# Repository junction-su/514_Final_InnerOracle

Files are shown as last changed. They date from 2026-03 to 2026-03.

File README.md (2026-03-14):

# 🔮 InnerOracle: Biometric Fortune Teller

## 1. Project Overview
**InnerOracle** is an interactive, tangible interface that translates physiological stress into mystical guidance. Unlike traditional fortune-telling machines that rely on random chance, InnerOracle utilizes **Galvanic Skin Response (GSR)** to measure the user's emotional arousal and provides a personalized Tarot reading through a mechanical dial and an OLED display.

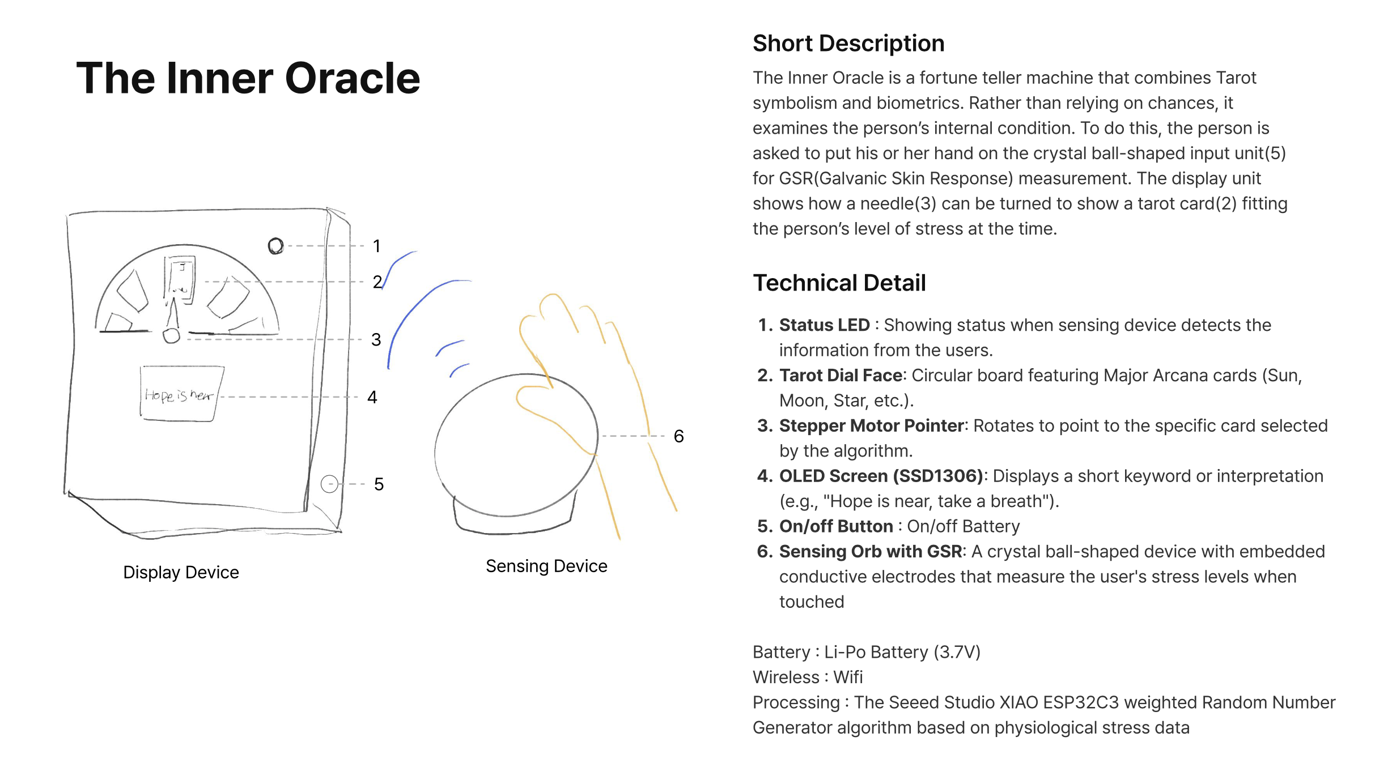
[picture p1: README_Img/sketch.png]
Concept Sketch
 

## 2. Technical Complexity & System Architecture
The system is built with a **Dual-Node Architecture** using two Seeed Studio XIAO ESP32-C3 microcontrollers communicating via the **ESP-NOW** wireless protocol.

### [Sensing Node]
* **Microcontroller**: Seeed Studio XIAO ESP32-C3
* **Sensor**: Grove GSR Sensor with custom Copper Tape Electrodes
* **Logic**: Implements an **Adaptive Baseline Tracking** algorithm to detect emotional triggers beyond skin resistance fluctuations.
* **Feedback**: Provides immediate visual feedback via NeoPixel LED (Rainbow effect).

### [Display Node]
* **Microcontroller**: Seeed Studio XIAO ESP32-C3
* **Actuator**: **X27.168 Stepper Motor** (Precision Gauge Motor)
* **Display**: 0.96" I2C SSD1306 OLED
* **Logic**: Receives real-time stress data and controls the physical needle with custom homing and calibration sequences.

## 3. Data Flow
`[User's Hand] -> [GSR Sensor] -> [Sensing XIAO] --(ESP-NOW Wireless)--> [Display XIAO] -> [X27 Motor & OLED]`

## 4. Hardware Fabrication
* **Custom PCB**: Designed and soldered at GIX Prototyping Labs.
* **Enclosure**: 2-part 3D printed housing ("The Orb" and "The Dial Box").
* **Power**: Powered by 3.7V 1000mAh LiPo batteries, optimized for up to 150+ hours of typical usage.

## 5. Repository Structure
* `/Sensing_Node`: Source code for GSR data processing and ESP-NOW transmission.
* `/Display_Node`: Source code for motor control, OLED UI, and data reception.

## 6. Budget Summary
* Total Project Cost: **$66.95**
* Key Components: GSR Sensor ($32.99), 1000mAh Batteries ($16.98), XIAO ESP32C3 ($10.99).

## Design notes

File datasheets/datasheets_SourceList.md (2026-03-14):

- Gear Stepper Motor(x27.168) : https://cdn-shop.adafruit.com/product-files/2424/2424.pdf // http://agr.ucoz.lv/files/SP_X27_e_C.pdf
- SSD1306(OLED) : https://cdn-shop.adafruit.com/datasheets/SSD1306.pdf
- Grove - GSR Sensor (Seeed Studio) : https://files.seeedstudio.com/wiki/Grove-GSR_Sensor/res/Grove-GSR_Sensor_WiKi.pdf
- ESP32-C3 : https://files.seeedstudio.com/wiki/XIAO_WiFi/Resources/esp32-c3_datasheet.pdf
- Li-Po Battery : https://cdn-shop.adafruit.com/product-files/1578/Datasheet.pdf
- Push Button(Tactile_Button_6mm) : https://cdn-shop.adafruit.com/datasheets/B3F-1000-Omron.pdf
- WS2812B(LED) : https://cdn-shop.adafruit.com/datasheets/WS2812B.pdf

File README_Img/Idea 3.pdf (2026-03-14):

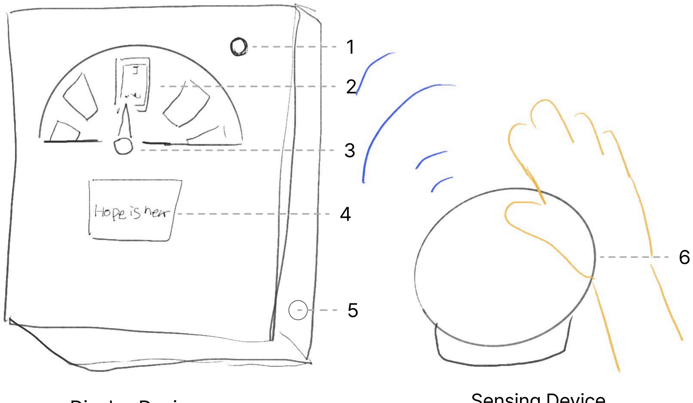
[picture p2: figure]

### Sensing Device Display Device

The Inner Oracle | Short Description

## Technical Detail

The Inner Oracle is a fortune teller machine that combines Tarot symbolism and biometrics. Rather than relying on chances, it examines the personˇs internal condition. To do this, the person is asked to put his or her hand on the crystal ball-shaped input unit(5) for GSR(Galvanic Skin Response) measurement. The display unit shows how a needle(3) can be turned to show a tarot card(2) fitting the personˇs level of stress at the time.

Status LED : Showing status when sensing device detects the information from the users.
Tarot Dial Face: Circular board featuring Major Arcana cards (Sun, Moon, Star, etc.).
Stepper Motor Pointer: Rotates to point to the specific card selected by the algorithm.
OLED Screen (SSD1306): Displays a short keyword or interpretation (e.g., "Hope is near, take a breath").
On/off Button : On/off Battery
Sensing Orb with GSR: A crystal ball-shaped device with embedded conductive electrodes that measure the user's stress levels when touched

Battery : Li-Po Battery (3.7V)
Wireless : Wifi
Processing : The Seeed Studio XIAO ESP32C3 weighted Random Number Generator algorithm based on physiological stress dat

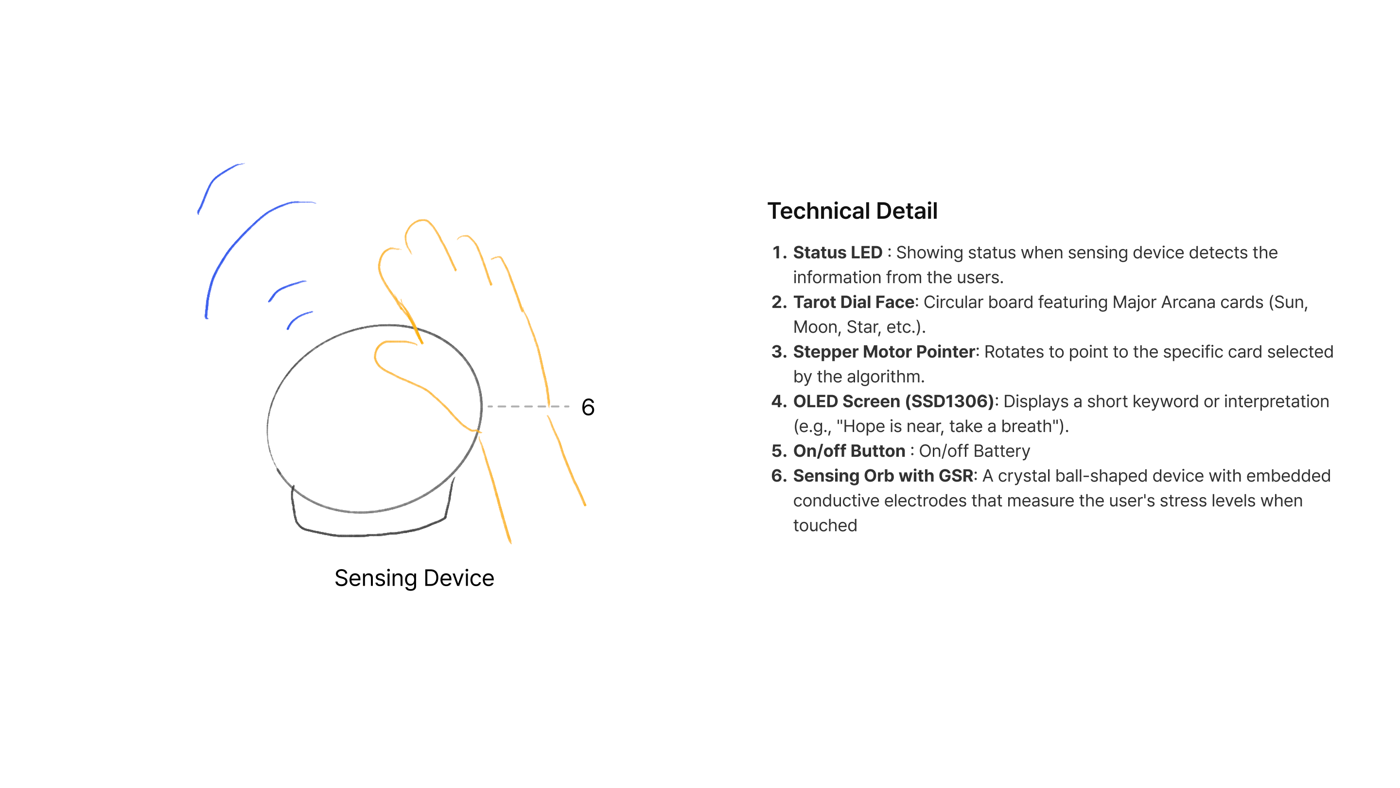
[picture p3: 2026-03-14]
README_Img/sensor_detail.png

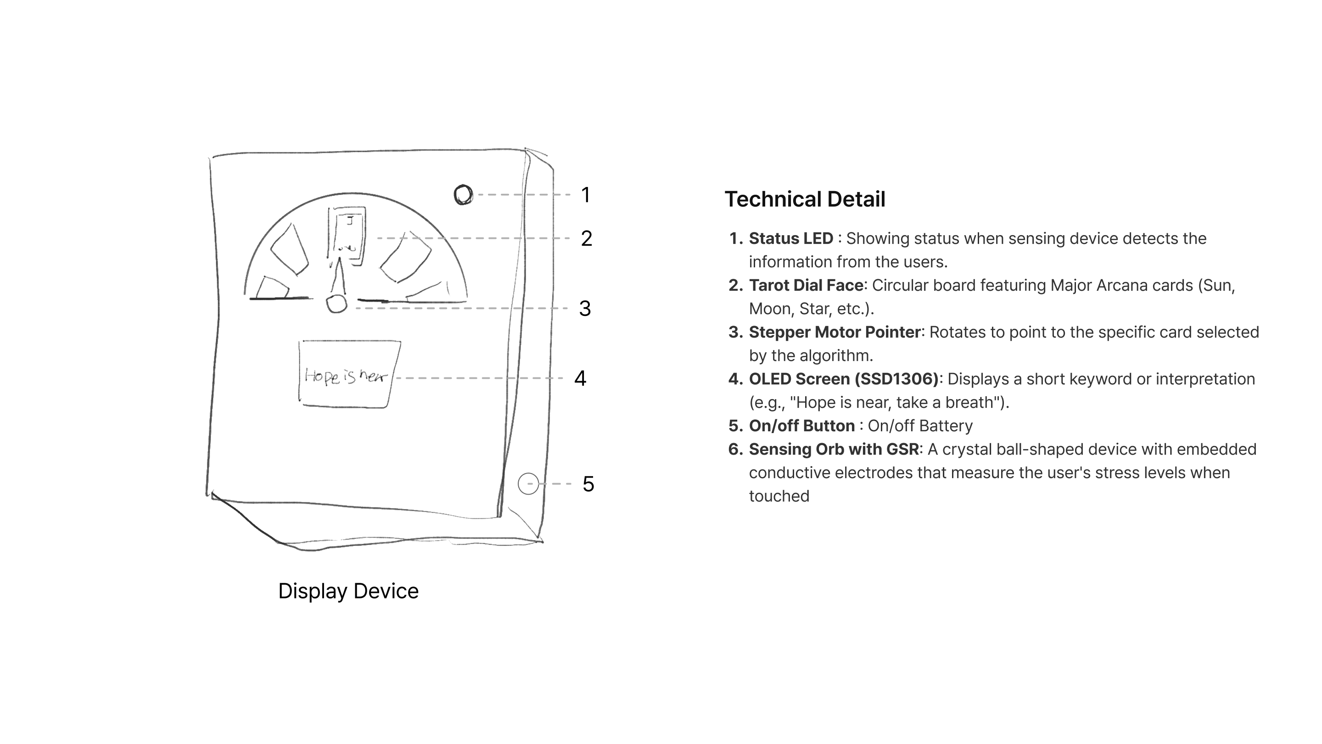
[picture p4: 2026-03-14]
README_Img/display_detail.png

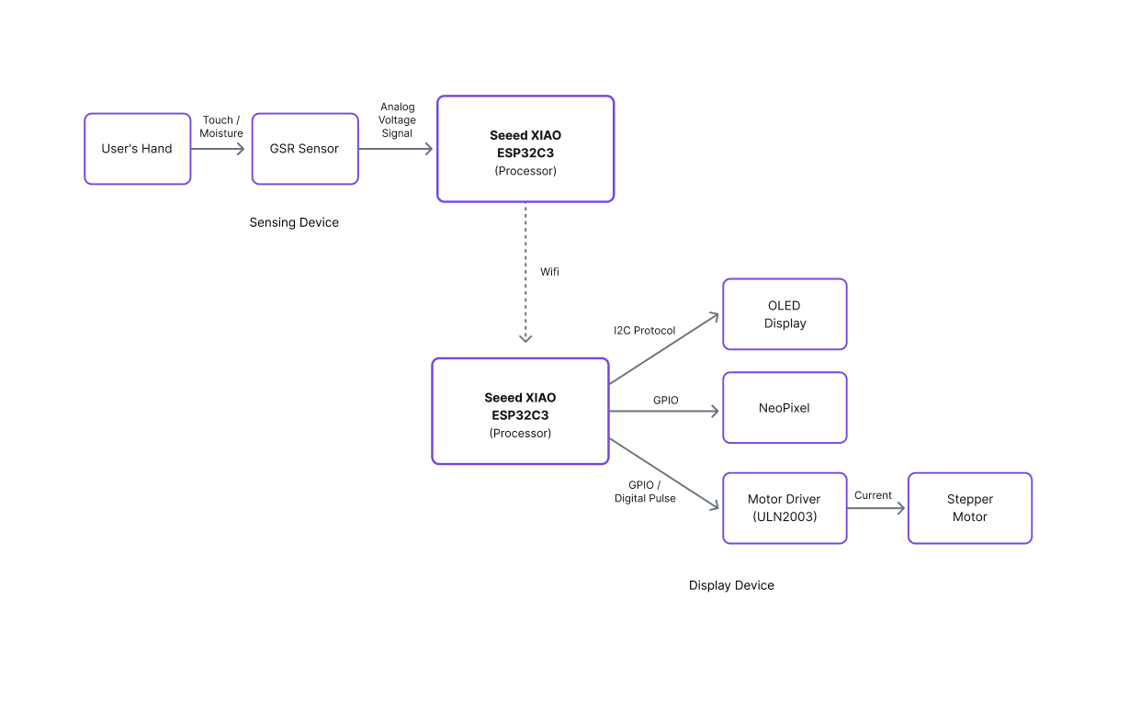
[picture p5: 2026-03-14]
README_Img/system_diagram_1.png

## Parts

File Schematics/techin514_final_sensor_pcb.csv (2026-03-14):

# | Reference | Qty | Value | Footprint | DNP
1 | Brd1 | 1 | SSD1306 | SSD1306:128x64OLED
2 | BT1, BT2 | 2 | Battery_Cell | Connector_JST:JST_PH_B2B-PH-K_1x02_P2.00mm_Vertical
3 | D1 | 1 | NeoPixel_THT | LED_THT:LED_Rectangular_W5.0mm_H2.0mm-3Pins
4 | J1 | 1 | SMD Grove | Connector:NS-Tech_Grove_1x04_P2mm_Vertical
5 | M1 | 1 | Stepper_Motor_bipolar | x27_stepper:x27_stepper_two_holes
6 | SW1, SW2 | 2 | SW_Push | Button_Switch_THT:SW_PUSH_6mm
7 | U1, U2 | 2 | ESP32-C3-XIAO | esp32c3:XIAO_ESP32

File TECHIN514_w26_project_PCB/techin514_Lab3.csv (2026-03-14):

# | Reference | Qty | Value | Footprint | DNP
1 | C1, C2 | 2 | 1uf | Capacitor_SMD:C_0805_2012Metric_Pad1.18x1.45mm_HandSolder
2 | C3 | 1 | 0.1uf | Capacitor_SMD:C_0805_2012Metric_Pad1.18x1.45mm_HandSolder
3 | C4 | 1 | 4.7uf | Capacitor_SMD:C_0805_2012Metric_Pad1.18x1.45mm_HandSolder
4 | D1 | 1 | LED | LED_SMD:LED_0805_2012Metric_Pad1.15x1.40mm_HandSolder
5 | J1 | 1 | Conn_01x04_Pin | Connector_PinSocket_2.54mm:PinSocket_1x04_P2.54mm_Vertical
6 | R1, R2 | 2 | 10k | Resistor_SMD:R_0805_2012Metric_Pad1.20x1.40mm_HandSolder
7 | R3 | 1 | 1k | Resistor_SMD:R_0805_2012Metric_Pad1.20x1.40mm_HandSolder
8 | U1 | 1 | MIC5376 | Package_TO_SOT_SMD:SOT-23-5
9 | U2 | 1 | LTR390 | OptoDevice:Lite-On_LTR-303ALS-01

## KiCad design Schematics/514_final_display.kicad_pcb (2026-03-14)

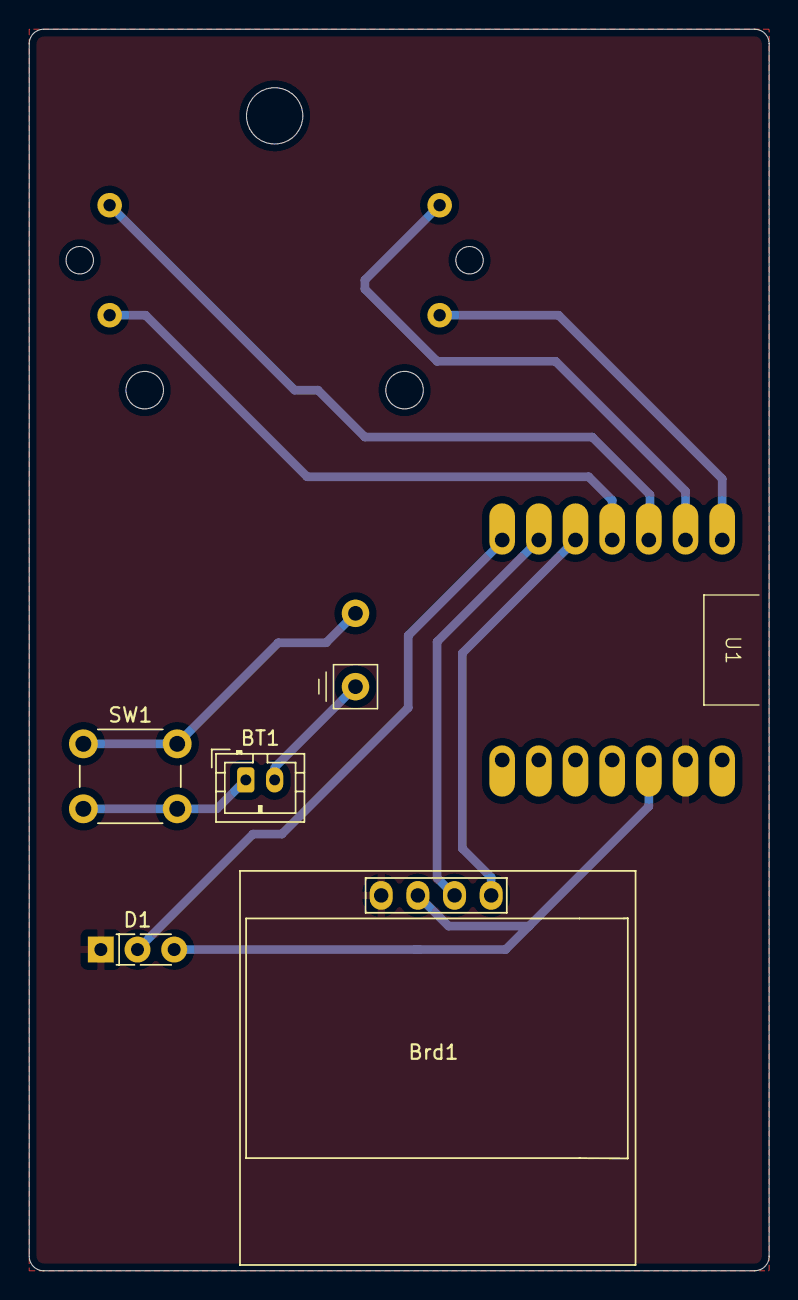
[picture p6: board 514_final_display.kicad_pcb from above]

Board: 2 copper layers, 51.2 x 86.0 mm, 6 parts (0 on the bottom side), 12 nets.

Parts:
BT1: Battery_Cell; JST_PH_B2B-PH-K_1x02_P2.00mm_Vertical
Brd1: SSD1306; 128x64OLED
D1: NeoPixel_THT; LED_Rectangular_W5.0mm_H2.0mm-3Pins
M1: Stepper_Motor_bipolar; x27_stepper_two_holes
SW1: SW_Push; SW_PUSH_6mm
U1: ESP32-C3-XIAO; XIAO_ESP32

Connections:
3V3: Brd1.2 (VCC), D1.3 (VDD), U1.12 (3V3)
+BATT: SW1.1, U1.15 (+BATT)
-BATT: BT1.2 (-), U1.16 (-BATT)
GND: Brd1.1 (GND), D1.1 (DOUT), U1.13 (GND)
unnamed: BT1.1 (+), SW1.2
unnamed: Brd1.3 (SCL), U1.6 (GPIO6_A5_D5_SCL)
unnamed: Brd1.4 (SDA), U1.5 (GPIO4_A3_D3_SDA)
unnamed: D1.2 (GND), U1.7 (GPIO43_TX_D6)
unnamed: M1.2 (-), U1.1 (GPIO1_A0_D0)
unnamed: M1.1, U1.2 (GPIO2_A1_D1)
unnamed: M1.3, U1.3 (GPIO3_A2_D2)
unnamed: M1.4, U1.4 (GPIO4_A3_D3)

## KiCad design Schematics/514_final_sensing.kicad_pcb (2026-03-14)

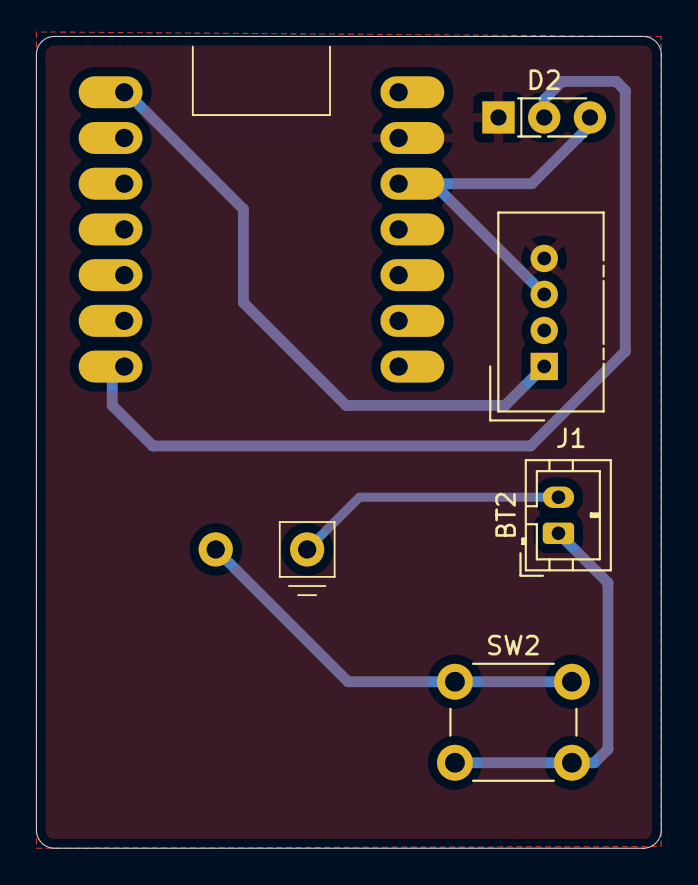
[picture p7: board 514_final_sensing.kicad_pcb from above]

Board: 2 copper layers, 34.7 x 45.1 mm, 5 parts (0 on the bottom side), 7 nets.

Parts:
BT2: Battery_Cell; JST_PH_B2B-PH-K_1x02_P2.00mm_Vertical
D2: NeoPixel_THT; LED_Rectangular_W5.0mm_H2.0mm-3Pins
J1: SMD Grove; NS-Tech_Grove_1x04_P2mm_Vertical
SW2: SW_Push; SW_PUSH_6mm
U2: ESP32-C3-XIAO; XIAO_ESP32

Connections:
3V3_S: D2.3 (VDD), J1.3, U2.12 (3V3)
+BATT_S: SW2.1, U2.15 (+BATT)
-BATT_S: BT2.2 (-), U2.16 (-BATT)
/SIG: J1.1, U2.1 (GPIO1_A0_D0)
GND: D2.1 (DOUT), J1.4, U2.13 (GND)
unnamed: BT2.1 (+), SW2.2
unnamed: D2.2 (GND), U2.7 (GPIO43_TX_D6)

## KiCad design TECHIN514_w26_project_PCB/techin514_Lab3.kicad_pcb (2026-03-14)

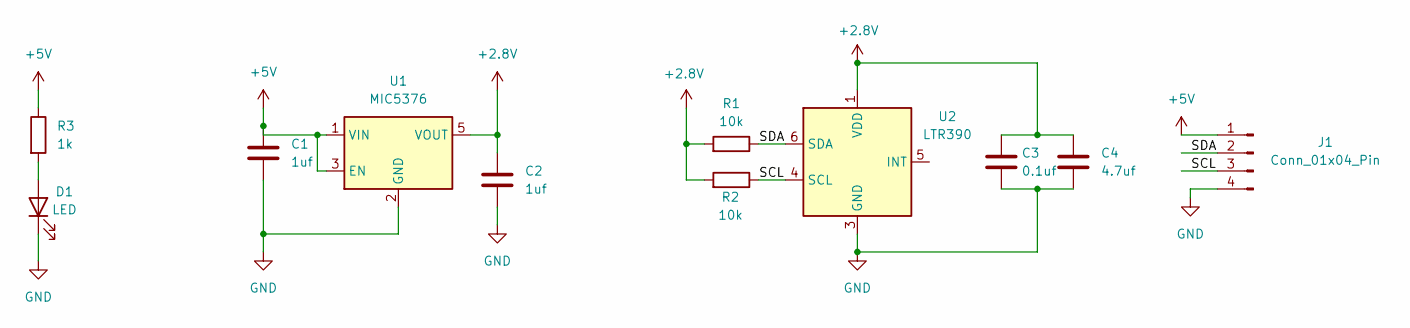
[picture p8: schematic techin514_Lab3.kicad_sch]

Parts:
C1, C2: 1uf; C_0805_2012Metric_Pad1.18x1.45mm_HandSolder
C3: 0.1uf; C_0805_2012Metric_Pad1.18x1.45mm_HandSolder
C4: 4.7uf; C_0805_2012Metric_Pad1.18x1.45mm_HandSolder
D1: LED; LED_0805_2012Metric_Pad1.15x1.40mm_HandSolder
J1: Conn_01x04_Pin; PinSocket_1x04_P2.54mm_Vertical
R1, R2: 10k; R_0805_2012Metric_Pad1.20x1.40mm_HandSolder
R3: 1k; R_0805_2012Metric_Pad1.20x1.40mm_HandSolder
U1: MIC5376; SOT-23-5
U2: LTR390; Lite-On_LTR-303ALS-01

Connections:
+2.8V: C2.1, C3.1, C4.1, R1.2, R2.2, U1.5 (VOUT), U2.1 (VDD)
+5V: C1.1, J1.1, R3.1, U1.1 (VIN), U1.3 (EN)
/SCL: J1.3, R2.1, U2.4 (SCL)
/SDA: J1.2, R1.1, U2.6 (SDA)
GND: C1.2, C2.2, C3.2, C4.2, D1.1 (K), J1.4, U1.2 (GND), U2.3 (GND)
unnamed: D1.2 (A), R3.2

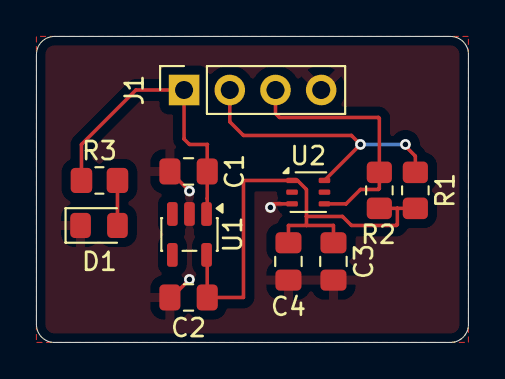
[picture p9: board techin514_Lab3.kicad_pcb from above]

Board: 2 copper layers, 24.0 x 17.0 mm, 11 parts (0 on the bottom side), 6 nets.

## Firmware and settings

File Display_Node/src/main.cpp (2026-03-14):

/**
 * InnerOracle - Receiver & Display Node
 * * Function: Receives stress levels via ESP-NOW and controls an X27 stepper motor 
 * to point at tarot card symbols on a physical dial. Updates an OLED display 
 * and NeoPixel LED based on the received data.
 */

#include <Arduino.h>
#include <esp_now.h>
#include <WiFi.h>
#include <SwitecX25.h> 
#include <Wire.h>
#include <Adafruit_GFX.h>
#include <Adafruit_SSD1306.h>
#include <Fonts/FreeSans9pt7b.h>
#include <Adafruit_NeoPixel.h>

// --- [Calibration Settings] ---
// Adjust homeOffset if the needle is misaligned at the starting position (The Fool).
int homeOffset = 100; 
// Adjust totalSteps to ensure the needle reaches the final position (The World) accurately.
int totalSteps = 950;  
// ------------------------------

// Motor instance (Steps, Pins: D2, D3, D0, D1)
SwitecX25 motor(1200, D2, D3, D0, D1); 

#define LED_PIN 20    
Adafruit_NeoPixel strip(1, LED_PIN, NEO_GRB + NEO_KHZ800);
Adafruit_SSD1306 display(128, 64, &Wire, -1);

// Global State Variables
volatile bool motorReadyToSpin = false;
int receivedStress = 0;
unsigned long lastOracleTime = 0; 

// Data structure for ESP-NOW
typedef struct struct_message { 
    int gsrValue; 
    int stressLevel; 
} struct_message;
struct_message incomingData;

int cardPositions[8]; 

const char* cardNames[8] = {"The Fool", "The Lovers", "The Hermit", "The Death", "The Devil", "The Tower", "The Star", "The World"};
const char* fortunes[8][3] = {
  {"Fresh Start", "Step Wisely", "Trust You"}, {"Deep Harmony", "Listen In", "You're Loved"},
  {"Peaceful Mind", "Quiet Down", "Just Breathe"}, {"New Horizon", "Let It Flow", "Better Days"},
  {"Strong Will", "Stay True", "Stay Gold"}, {"Clear View", "Hold Firm", "Rise Again"},
  {"Bright Hope", "Follow Light", "Still Shine"}, {"Peak State", "Keep Going", "Proud of You"}
};

uint32_t cardColors[8] = {
  strip.Color(255, 255, 255), strip.Color(255, 50, 100), strip.Color(255, 150, 0),
  strip.Color(100, 0, 255), strip.Color(255, 0, 0), strip.Color(255, 255, 0),
  strip.Color(0, 150, 255), strip.Color(0, 255, 150)
};

// --- Helper Functions ---

/**
 * Handles centered text alignment on the OLED with dynamic font scaling.
 */
void printLargeCentered(String text, int yPos) {
  int16_t x1, y1; uint16_t w, h;
  display.setFont(&FreeSans9pt7b);
  display.setTextSize(1);
  display.getTextBounds(text, 0, 0, &x1, &y1, &w, &h);
  
  // Scale down font size if the text exceeds screen width
  if (w > 120) { 
    display.setFont(NULL); 
    display.setTextSize(2); 
    display.getTextBounds(text, 0, 0, &x1, &y1, &w, &h); 
    yPos -= 5; 
  }
  display.setCursor((128 - w) / 2, yPos);
  display.print(text);
}

/**
 * Displays onboarding instructions for the user.
 */
void printOnboarding() {
  display.clearDisplay();
  display.setFont(&FreeSans9pt7b);
  printLargeCentered("Place hand", 25);
  printLargeCentered("on the Orb", 50);
  display.display();
}

/**
 * Opening sequence: Title typing effect and motor/LED calibration ceremony.
 */
void startupAnimation() {
  display.clearDisplay();
  display.setTextColor(SSD1306_WHITE);
  
  // 1. Staggered typing effect for the title
  String t1 = "Inner"; String t2 = "Oracle";
  for(int i=1; i<=t1.length(); i++) {
    display.clearDisplay();
    printLargeCentered(t1.substring(0, i), 25);
    display.display(); delay(100);
  }
  delay(300);
  for(int i=1; i<=t2.length(); i++) {
    display.clearDisplay();
    printLargeCentered(t1, 25);
    printLargeCentered(t2.substring(0, i), 50);
    display.display(); delay(100);
  }

  // 2. Needle sweep and progress bar (Ceremony)
  motor.setPosition(cardPositions[7]); 
  for (int i = 0; i <= 100; i++) {
    motor.update();
    display.drawRect(20, 58, 88, 4, SSD1306_WHITE);
    display.fillRect(20, 58, (i * 88 / 100), 4, SSD1306_WHITE);
    display.display();
    strip.setPixelColor(0, strip.Color(i, i, i)); strip.show();
    // Maintain torque during movement
    for(int j=0; j<15; j++) { motor.update(); delay(2); } 
  }

  // 3. Return to Home position (The Fool)
  motor.setPosition(cardPositions[0]);
  while (motor.currentStep != motor.targetStep) {
    motor.update();
    strip.setPixelColor(0, strip.Color(100, 100, 100)); strip.show();
    delay(2);
  }
}

/**
 * Callback function executed when data is received via ESP-NOW.
 */
void OnDataRecv(const uint8_t * mac, const uint8_t *ptr, int len) {
  memcpy(&incomingData, ptr, sizeof(incomingData));
  receivedStress = incomingData.stressLevel;
  motorReadyToSpin = true;
}

void setup() {
  strip.begin(); 
  strip.setBrightness(150);
  display.begin(SSD1306_SWITCHCAPVCC, 0x3C);
  
  // Pre-calculate step positions for each card
  int gap = totalSteps / 7;
  for (int i = 0; i < 8; i++) {
    cardPositions[i] = homeOffset + (i * gap);
  }

  motor.zero(); // Physical homing sequence
  delay(500);
  startupAnimation();
  printOnboarding();

  WiFi.mode(WIFI_STA);
  esp_now_init();
  esp_now_register_recv_cb(OnDataRecv);
}

void loop() {
  motor.update(); // Continuous motor update

  if (motorReadyToSpin && (millis() - lastOracleTime > 5000)) {
    motorReadyToSpin = false;
    strip.setPixelColor(0, strip.Color(0, 50, 200)); strip.show(); // Analyzing status (Blue)
    
    display.clearDisplay();
    display.setFont(NULL);
    display.setCursor(25, 30); display.print("Reading Soul...");
    display.display();

    int targetIdx = random(0, 8); // Select a random tarot card

    // Special animation for "The Fool" (Index 0): Full sweep before stopping
    if (targetIdx == 0) {
      motor.setPosition(cardPositions[7]);
      while (motor.currentStep != motor.targetStep) { motor.update(); delay(2); }
      delay(300);
    }

    // Move to target card position
    motor.setPosition(cardPositions[targetIdx]);
    while (motor.currentStep != motor.targetStep) { motor.update(); delay(3); }

    // Final result display and LED update
    strip.setPixelColor(0, cardColors[targetIdx]); strip.show();
    display.clearDisplay();
    display.setFont(NULL);
    display.setCursor(0, 0); display.print(cardNames[targetIdx]);
    display.drawLine(0, 10, 128, 10, SSD1306_WHITE);
    printLargeCentered(fortunes[targetIdx][receivedStress], 45);
    display.display();

    delay(9000); // Wait for the user to read the fortune

    // Reset to idle state: Turn off LED and return home
    strip.setPixelColor(0, 0); strip.show();
    display.clearDisplay();
    printLargeCentered("Resetting...", 38);
    display.display();

    motor.setPosition(cardPositions[0]); 
    while (motor.currentStep != motor.targetStep) { motor.update(); delay(2); }

    printOnboarding();
    lastOracleTime = millis();
  }
}

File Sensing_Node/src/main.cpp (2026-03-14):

/**
 * InnerOracle - Sensing Node
 * Function: Detects GSR (Galvanic Skin Response) and sends stress data via ESP-NOW.
 */

#include <Arduino.h>
#include <esp_now.h>
#include <WiFi.h>
#include <Adafruit_NeoPixel.h>

const int SENSOR_PIN = 2;    // GSR Sensor Pin (GPIO 2)
const int LED_PIN = D3;      // NeoPixel Pin (D3)
const int NUM_LEDS = 2;    
const int SENSITIVITY = 25;  // Delta value for trigger detection

Adafruit_NeoPixel strip(NUM_LEDS, LED_PIN, NEO_GRB + NEO_KHZ800);

// Data structure for ESP-NOW communication
typedef struct struct_message {
  int gsrValue;
  int stressLevel;
} struct_message;
struct_message myData;

int baseline = 0;

// Visual feedback: Rainbow cycle effect
void startRainbowEffect(int duration_ms) {
  unsigned long startTime = millis();
  uint32_t firstPixelHue = 0;
  while (millis() - startTime < duration_ms) {
    strip.setPixelColor(0, strip.gamma32(strip.ColorHSV(firstPixelHue)));
    strip.show();
    firstPixelHue += 1024; 
    delay(20); 
  }
}

void setup() {
  Serial.begin(115200);
  analogSetAttenuation(ADC_11db);
  
  strip.begin();
  strip.setBrightness(255); // Max brightness for showcase visibility
  strip.show();

  WiFi.mode(WIFI_STA);
  if (esp_now_init() != ESP_OK) return;

  // Broadcast address setup for peer communication
  uint8_t broadcastAddress[] = {0xFF, 0xFF, 0xFF, 0xFF, 0xFF, 0xFF}; 
  esp_now_peer_info_t peerInfo = {};
  memcpy(peerInfo.peer_addr, broadcastAddress, 6);
  peerInfo.channel = 0;  
  peerInfo.encrypt = false;
  esp_now_add_peer(&peerInfo);

  // Initial calibration for sensor baseline
  long sum = 0;
  for(int i=0; i<30; i++) { sum += analogRead(SENSOR_PIN); delay(20); }
  baseline = sum / 30;
}

void loop() {
  int currentVal = analogRead(SENSOR_PIN);
  
  // Trigger condition: current value exceeds adaptive baseline + sensitivity
  if (currentVal > (baseline + SENSITIVITY)) {
    // 1. Alert: Red flash then Rainbow effect
    strip.setPixelColor(0, strip.Color(255, 0, 0)); 
    strip.show();
    delay(100);
    startRainbowEffect(3000); 

    // 2. Data Transmission
    myData.gsrValue = currentVal;
    myData.stressLevel = random(0, 3); // 0:Low, 1:Mid, 2:High
    uint8_t broadcastAddress[] = {0xFF, 0xFF, 0xFF, 0xFF, 0xFF, 0xFF}; 
    esp_now_send(broadcastAddress, (uint8_t *) &myData, sizeof(myData));

    // 3. Reset and Cool-down
    strip.setPixelColor(0, strip.Color(150, 150, 150)); strip.show();
    delay(5000); 
    baseline = analogRead(SENSOR_PIN); // Recalibrate baseline after trigger
  } else {
    // Idle state: Subtle white light
    strip.setPixelColor(0, strip.Color(150, 150, 150)); strip.show();
    // Smooth baseline tracking
    baseline = (baseline * 0.99) + (currentVal * 0.01); 
    delay(50);
  }
}

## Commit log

2026-01-20 Update datasheet links in datasheets.md
    Updated datasheet links for Gear Stepper Motor Driver and added ESP32-C3 datasheet.
2026-01-20 Add datasheets for Li-Po Battery, Push Button, and WS2812B
2026-01-20 add uln200,ws2812b,lipo,esp32c3,ssd1306,cx28byj48
2026-01-25 upload final schematics and bom
    [techin514_final_sensor_pcb.csv, techin514_final_sensor_pcb.kicad_pcb, techin514_final_sensor_pcb.kicad_sch]
2026-01-25 make a pcb lab folder
2026-01-25 upload pcb lab sch and bom
    [techin514_Lab3.csv, techin514_Lab3.kicad_pcb, techin514_Lab3.kicad_sch]
2026-01-29 Upload Kicad files and bom
    [techin514_Lab3.csv, techin514_Lab3.kicad_pcb, techin514_Lab3.kicad_sch]
2026-02-04 Revise Gear Stepper Motor Driver Pack details
    Updated the Gear Stepper Motor Driver Pack entry with a new link and removed outdated entries.
2026-02-04 Update links for stepper motor and LED datasheets
2026-02-07 Fix link for Gear Stepper Motor Driver Pack
    Updated the link for Gear Stepper Motor Driver Pack.
2026-02-07 Update Gear Stepper Motor description in datasheet
2026-02-28 Add ESP-NOW GSR sensor data transmission
